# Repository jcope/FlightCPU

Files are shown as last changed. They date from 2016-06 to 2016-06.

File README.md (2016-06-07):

# FlightCPU
An embedded data logger for high altitude balloons

The Flight CPU is designed as a data logger for High Altitude Balloons. It is designed around the ATMEGA328P so it can easily be developed using Arduino tools. Most sensor modules communicate with the uC using I2C with the exception of the Humidity/Temp sensor which uses SPI. The data is then logged on the MicroSD card. 

Sensors include: Gyroscope, Compass, Temp/Humidity, Barometer.

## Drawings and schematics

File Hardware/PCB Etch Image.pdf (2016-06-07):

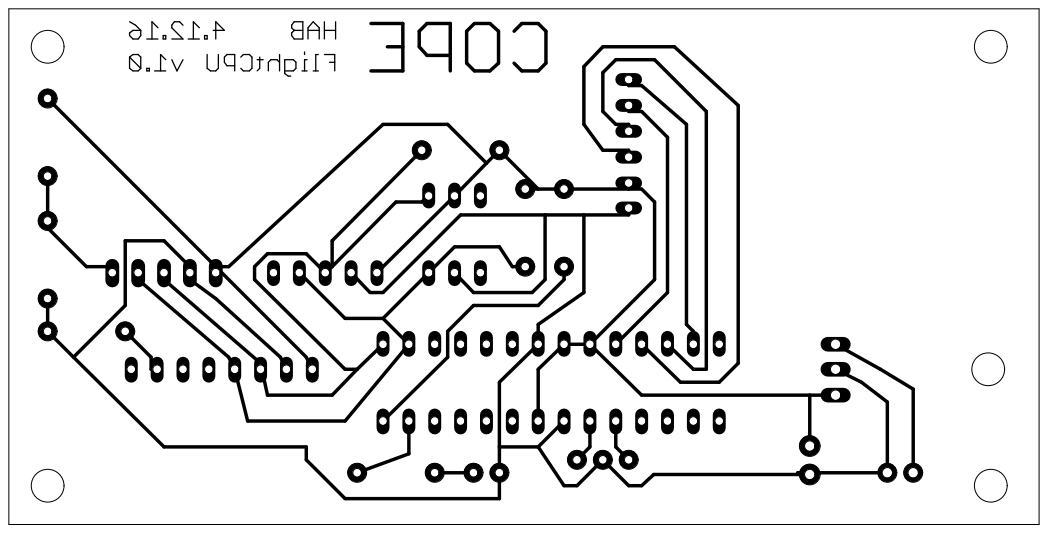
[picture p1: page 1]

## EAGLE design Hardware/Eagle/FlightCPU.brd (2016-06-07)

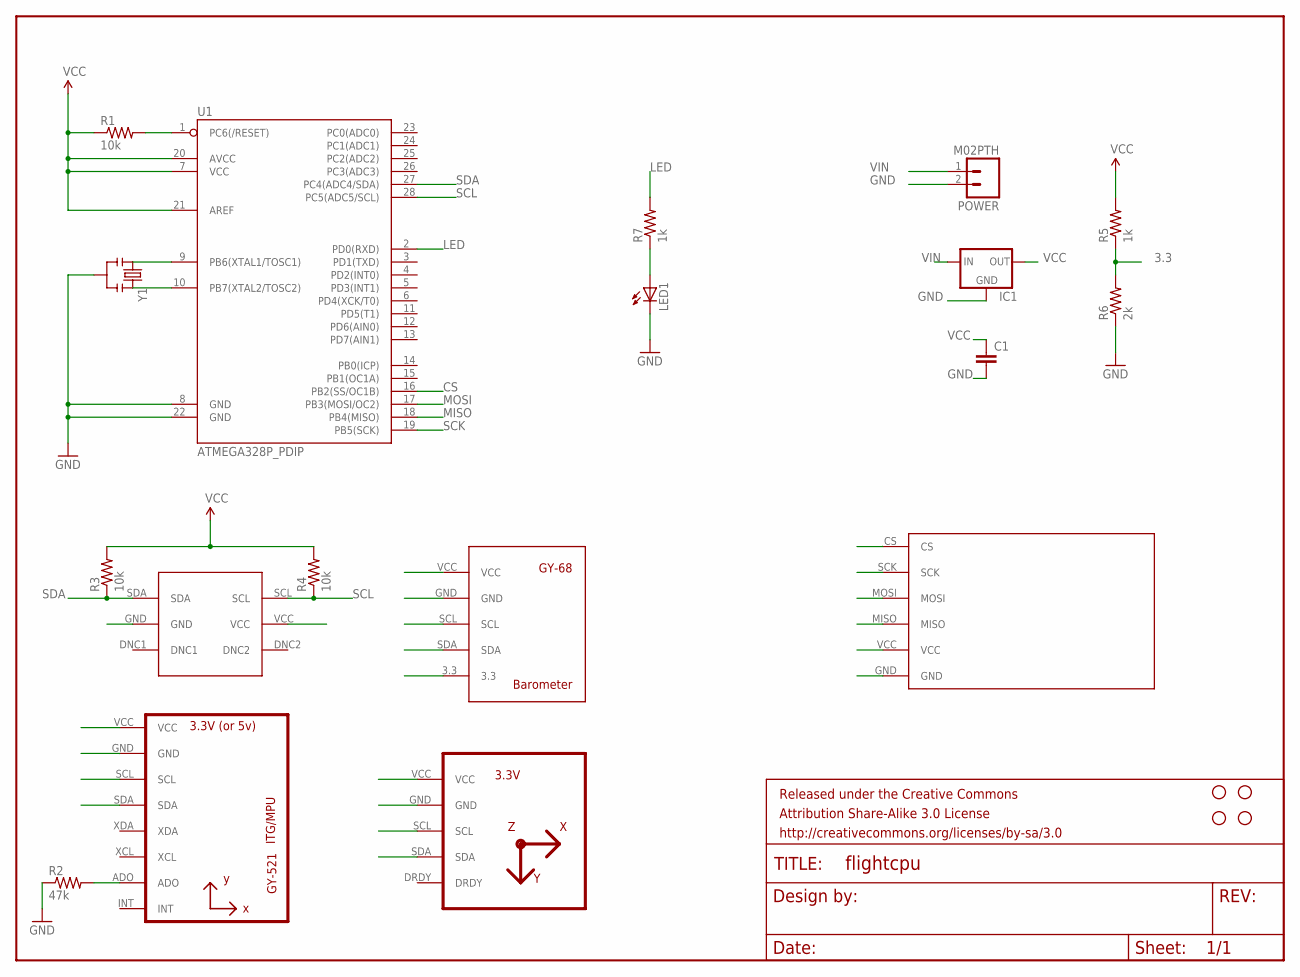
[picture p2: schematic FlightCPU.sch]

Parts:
C1: CAPKIT; CAP-PTH-SMALL-KIT
FRAME1: FRAME-LETTER; CREATIVE_COMMONS
IC1: V_REG_78XXSIDE; 78XXL
LED1: LED3MM
POWER: M02PTH; 1X02
R1, R3, R4: 10k; AXIAL-0.3
R2: 47k; AXIAL-0.3
R5, R7: 1k; AXIAL-0.3
R6: 2k; AXIAL-0.3
STANDOFF1, STANDOFF2, STANDOFF3, STANDOFF4: STAND-OFF
U1: ATMEGA328P_PDIP; DIL28-3
U2: GY-521MPU6050; GY-521
U3: HMC5883LGY-271; GY-271
U$1: SI7020_DIP; SI7020
U$2: GY-68
U$3: MICRO_SD; MICROSD
Y1: RESONATORPTH; RESONATOR-PTH

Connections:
3.3: R5.P$1 (1), R6.P$2 (2), U$2.3.3
CS: U1.16 (PB2(SS/OC1B)), U$3.CS
GND: C1.2, IC1.GND, LED1.K (C), POWER.2, R2.P$1 (1), R6.P$1 (1), U1.8 (GND), U1.22 (GND), U2.GND, U3.GND, U$1.GND, U$2.GND, U$3.GND, Y1.2
LED: R7.P$2 (2), U1.2 (PD0(RXD))
MISO: U1.18 (PB4(MISO)), U$3.MISO
MOSI: U1.17 (PB3(MOSI/OC2)), U$3.MOSI
unnamed: R1.P$2 (2), U1.1 (PC6(/RESET))
unnamed: U1.9 (PB6(XTAL1/TOSC1)), Y1.1
unnamed: U1.10 (PB7(XTAL2/TOSC2)), Y1.3
unnamed: LED1.A, R7.P$1 (1)
unnamed: R2.P$2 (2), U2.ADO
SCK: U1.19 (PB5(SCK)), U$3.SCK
SCL: R4.P$1 (1), U1.28 (PC5(ADC5/SCL)), U2.SCL, U3.SCL, U$1.SCL, U$2.SCL
SDA: R3.P$1 (1), U1.27 (PC4(ADC4/SDA)), U2.SDA, U3.SDA, U$1.SDA, U$2.SDA
VCC: C1.1, IC1.OUT, R1.P$1 (1), R3.P$2 (2), R4.P$2 (2), R5.P$2 (2), U1.7 (VCC), U1.20 (AVCC), U1.21 (AREF), U2.VCC, U3.VCC, U$1.VCC, U$2.VCC, U$3.VCC
VIN: IC1.IN, POWER.1

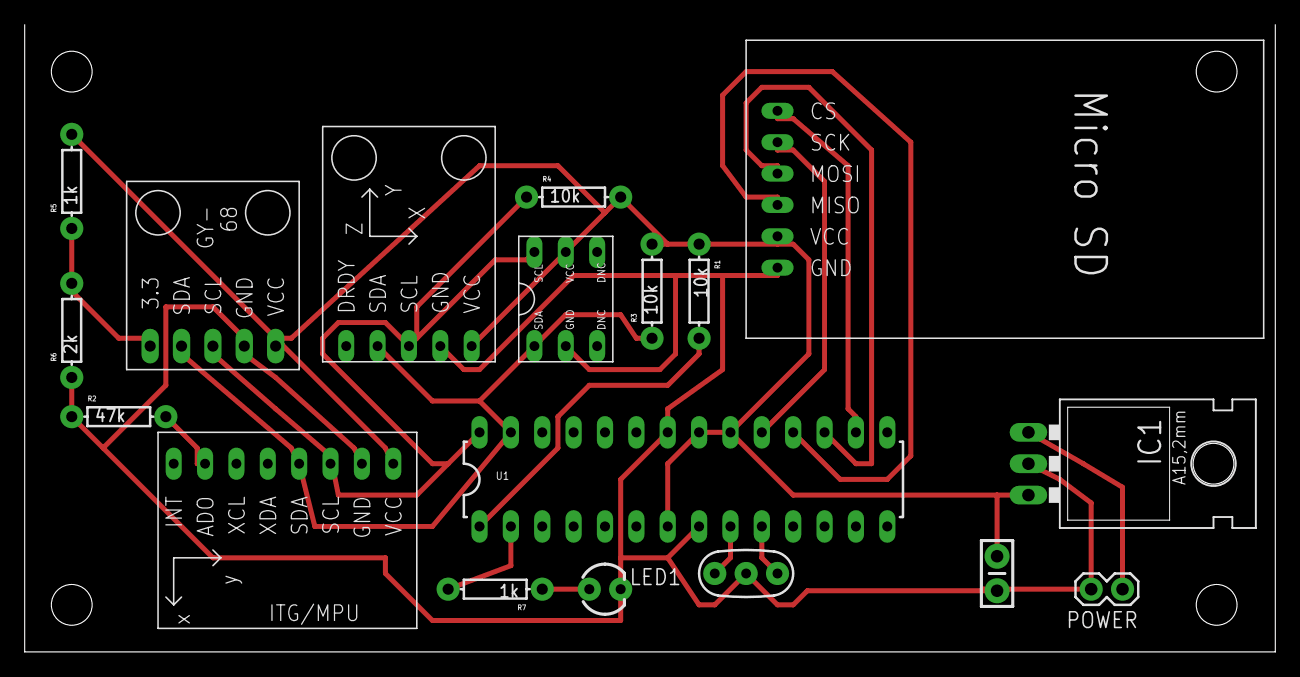
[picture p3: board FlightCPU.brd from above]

Board: 2 copper layers, 101.3 x 50.8 mm, 23 parts (0 on the bottom side), 16 nets.

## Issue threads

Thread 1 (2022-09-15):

SD Card Issues

svetgeorgiev, 2022-09-15:
main: In function 'void writeToSD(double)':
main:343: error: no matching function for call to 'SDClass::open(const __FlashStringHelper*, int)'
   dFile = SD.open(F("COPE01.txt"), FILE_WRITE);
                                              ^
In file included from C:\Users\B0lero\Desktop\main\main.ino:74:0:
C:\Program Files (x86)\Arduino\hardware\teensy\avr\libraries\SD\src/SD.h:181:7: note: candidate: virtual File SDClass::open(const char*, uint8_t)
  File open(const char *filepath, uint8_t mode = FILE_READ) {
       ^
C:\Program Files (x86)\Arduino\hardware\teensy\avr\libraries\SD\src/SD.h:181:7: note:   no known conversion for argument 1 from 'const __FlashStringHelper*' to 'const char*'
main: In function 'void writeToSD(double, int)':
main:359: error: no matching function for call to 'SDClass::open(const __FlashStringHelper*, int)'
   dFile = SD.open(F("COPE01.txt"), FILE_WRITE);
                                              ^
In file included from C:\Users\B0lero\Desktop\main\main.ino:74:0:
C:\Program Files (x86)\Arduino\hardware\teensy\avr\libraries\SD\src/SD.h:181:7: note: candidate: virtual File SDClass::open(const char*, uint8_t)
  File open(const char *filepath, uint8_t mode = FILE_READ) {
       ^
C:\Program Files (x86)\Arduino\hardware\teensy\avr\libraries\SD\src/SD.h:181:7: note:   no known conversion for argument 1 from 'const __FlashStringHelper*' to 'const char*'
main: In function 'void writeToSD(String)':
main:375: error: no matching function for call to 'SDClass::open(const __FlashStringHelper*, int)'
   dFile = SD.open(F("COPE01.txt"), FILE_WRITE);
                                              ^
In file included from C:\Users\B0lero\Desktop\main\main.ino:74:0:
C:\Program Files (x86)\Arduino\hardware\teensy\avr\libraries\SD\src/SD.h:181:7: note: candidate: virtual File SDClass::open(const char*, uint8_t)
  File open(const char *filepath, uint8_t mode = FILE_READ) {
       ^
C:\Program Files (x86)\Arduino\hardware\teensy\avr\libraries\SD\src/SD.h:181:7: note:   no known conversion for argument 1 from 'const __FlashStringHelper*' to 'const char*'
main: In function 'void writeToSDln(double)':
main:395: error: no matching function for call to 'SDClass::open(const __FlashStringHelper*, int)'
   dFile = SD.open(F("COPE01.txt"), FILE_WRITE);
                                              ^
In file included from C:\Users\B0lero\Desktop\main\main.ino:74:0:
C:\Program Files (x86)\Arduino\hardware\teensy\avr\libraries\SD\src/SD.h:181:7: note: candidate: virtual File SDClass::open(const char*, uint8_t)
  File open(const char *filepath, uint8_t mode = FILE_READ) {
       ^
C:\Program Files (x86)\Arduino\hardware\teensy\avr\libraries\SD\src/SD.h:181:7: note:   no known conversion for argument 1 from 'const __FlashStringHelper*' to 'const char*'
main: In function 'void writeToSDln(double, int)':
main:411: error: no matching function for call to 'SDClass::open(const __FlashStringHelper*, int)'
   dFile = SD.open(F("COPE01.txt"), FILE_WRITE);
                                              ^
In file included from C:\Users\B0lero\Desktop\main\main.ino:74:0:
C:\Program Files (x86)\Arduino\hardware\teensy\avr\libraries\SD\src/SD.h:181:7: note: candidate: virtual File SDClass::open(const char*, uint8_t)
  File open(const char *filepath, uint8_t mode = FILE_READ) {
       ^
C:\Program Files (x86)\Arduino\hardware\teensy\avr\libraries\SD\src/SD.h:181:7: note:   no known conversion for argument 1 from 'const __FlashStringHelper*' to 'const char*'
main: In function 'void writeToSDln(String)':
main:427: error: no matching function for call to 'SDClass::open(const __FlashStringHelper*, int)'
   dFile = SD.open(F("COPE01.txt"), FILE_WRITE);
                                              ^
In file included from C:\Users\B0lero\Desktop\main\main.ino:74:0:
C:\Program Files (x86)\Arduino\hardware\teensy\avr\libraries\SD\src/SD.h:181:7: note: candidate: virtual File SDClass::open(const char*, uint8_t)
  File open(const char *filepath, uint8_t mode = FILE_READ) {
       ^

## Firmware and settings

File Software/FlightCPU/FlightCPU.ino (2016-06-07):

//Common
#include "Wire.h"
#include "I2Cdev.h"

/********************
    Pressure
*/
#include <SFE_BMP180.h>
// You will need to create an SFE_BMP180 object, here called "pressure":
SFE_BMP180 pressure;
double baselineP; // baseline pressure
void pressureFunc();
void getTempPressure(double &T, double &P);


/********************
    Compass-Magmometer
*/

#include "HMC5883L.h"
// class default I2C address is 0x1E
// specific I2C addresses may be passed as a parameter here
// this device only supports one I2C address (0x1E)
HMC5883L mag;
int16_t mx, my, mz;
void compassFunc();



/********************
    Acceler-Gyro
*/
#include "MPU6050.h"
// class default I2C address is 0x68
// specific I2C addresses may be passed as a parameter here
// AD0 low = 0x68 (default for InvenSense evaluation board)
// AD0 high = 0x69
MPU6050 accelgyro;
//MPU6050 accelgyro(0x69); // <-- use for AD0 high
int16_t ax, ay, az;
int16_t gx, gy, gz;

// uncomment "OUTPUT_READABLE_ACCELGYRO" if you want to see a tab-separated
// list of the accel X/Y/Z and then gyro X/Y/Z values in decimal. Easy to read,
// not so easy to parse, and slow(er) over UART.
#define OUTPUT_READABLE_ACCELGYRO

// uncomment "OUTPUT_BINARY_ACCELGYRO" to send all 6 axes of data as 16-bit
// binary, one right after the other. This is very fast (as fast as possible
// without compression or data loss), and easy to parse, but impossible to read
// for a human.
//#define OUTPUT_BINARY_ACCELGYRO

void accelGyroFunc();
void accelGyroFactoryReset();


/********************
   Humidity/Temp
*/
void humdTempFunc();


/********************
   SD card datalogger
   SD card attached to SPI bus as follows:
 ** MOSI - pin 11
 ** MISO - pin 12
 ** CLK - pin 13
 ** CS - pin 4
*/
#include <SPI.h>
#include <SD.h>
const int chipSelect = 4;
File dataFile;
void initDataFile();
void writeToSD(String dataLine);
void writeToSD(double dataLine);
void writeToSDln(double dataLine);
void writeToSDln(String dataLine);


/********************
    IO
*/
#define LED_PIN 0
bool blinkState = false;
unsigned long t;


void setup() {
  // Initialize the LED- Must be first for data indicators
  pinMode(LED_PIN, OUTPUT);

  // join I2C bus (I2Cdev library doesn't do this automatically)
  Wire.begin();

  //Initialize SD Card
  initDataFile();

  // initialize device
  mag.initialize();
  accelgyro.initialize();

  // verify connection
  writeToSDln(mag.testConnection() ? F("HMC5883L connection successful") : F("HMC5883L connection failed"));      //Compass
  writeToSDln(pressure.begin() ? F("BMP180 connection successful") : F("BMP180 connection failed"));              //Barometer
  writeToSDln(accelgyro.testConnection() ? F("MPU6050 connection successful") : F("MPU6050 connection failed"));  //AccellGyro

  //Calibrate any baselines
  // Get the baseline pressure:
  double T;// through away temp
  getTempPressure(T,baselineP);
}

void loop() {
  //Log time
  t = millis();
  writeToSD("t,");
  writeToSDln(t);
  
  blinkState = !blinkState;
  digitalWrite(LED_PIN, blinkState);
  compassFunc();
  delay(250);
  
  blinkState = !blinkState;
  digitalWrite(LED_PIN, blinkState);
  accelGyroFunc();
  delay(250);
  

  
  humdTempFunc();
  delay(500);
  

  compassFunc();
  delay(250);
  accelGyroFunc();
  delay(250);

  pressureFunc();
  delay(500);
}

//C,mx,my,mx,h
//Compass,magX,magY,magZ,heading
void compassFunc() {
  writeToSD(F("C,"));
  // read raw heading measurements from device
  mag.getHeading(&mx, &my, &mz);

  // display tab-separated gyro x/y/z values
  writeToSD(mx); writeToSD(",");
  writeToSD(my); writeToSD(F(","));
  writeToSD(mz); writeToSD(F(","));

  // To calculate heading in degrees. 0 degree indicates North
  float heading = atan2(my, mx);
  if (heading < 0) {
    heading += 2 * M_PI;
  }
  writeToSDln(heading * 180 / M_PI);
}

//B,t,p,a
//Barameter,Temp(f),Pressure(mb),Altitude(ft)
void pressureFunc() {
  double T, P, A;
  writeToSD(F("B,"));

  getTempPressure(T, P);

  //We now have Pessure, Temp.. Go Calculate Altitude
  //Pressure
  writeToSD(P, 2);
  //Temp
  writeToSD(F(","));
  writeToSD((9.0 / 5.0)*T + 32.0, 2);
  //Altitude
  writeToSD(F(","));
  A = pressure.altitude(P, baselineP);
  writeToSDln(A * 3.28084, 0); //Altitude in ft
}
void getTempPressure(double &T, double &P) {
  char status;
  // You must first get a temperature measurement to perform a pressure reading.

  // Start a temperature measurement:
  // If request is successful, the number of ms to wait is returned.
  // If request is unsuccessful, 0 is returned.

  status = pressure.startTemperature();
  if (status != 0)
  {
    // Wait for the measurement to complete:

    delay(status);

    // Retrieve the completed temperature measurement:
    // Note that the measurement is stored in the variable T.
    // Use '&T' to provide the address of T to the function.
    // Function returns 1 if successful, 0 if failure.

    status = pressure.getTemperature(T);
    if (status != 0)
    {
      // Start a pressure measurement:
      // The parameter is the oversampling setting, from 0 to 3 (highest res, longest wait).
      // If request is successful, the number of ms to wait is returned.
      // If request is unsuccessful, 0 is returned.

      status = pressure.startPressure(3);
      if (status != 0)
      {
        // Wait for the measurement to complete:
        delay(status);

        // Retrieve the completed pressure measurement:
        // Note that the measurement is stored in the variable P.
        // Use '&P' to provide the address of P.
        // Note also that the function requires the previous temperature measurement (T).
        // (If temperature is stable, you can do one temperature measurement for a number of pressure measurements.)
        // Function returns 1 if successful, 0 if failure.

        status = pressure.getPressure(P, T);
        if (status != 0)
        {



        }
        else writeToSDln(F("e1")); //error retrieving pressure
      }
      else writeToSDln(F("e2")); //error starting pressure
    }
    else writeToSDln(F("e3")); //error retrieving temp
  }
  else writeToSDln(F("e4")); //error starting temp
}
//ax,ay,az,gz,gx,gy
void accelGyroFunc() {
  // read raw accel/gyro measurements from device
  accelgyro.getMotion6(&ax, &ay, &az, &gx, &gy, &gz);

  // these methods (and a few others) are also available
  //accelgyro.getAcceleration(&ax, &ay, &az);
  //accelgyro.getRotation(&gx, &gy, &gz);

#ifdef OUTPUT_READABLE_ACCELGYRO
  // display tab-separated accel/gyro x/y/z values
  writeToSD("a/g,");
  writeToSD(ax); writeToSD(F(","));
  writeToSD(ay); writeToSD(F(","));
  writeToSD(az); writeToSD(F(","));
  writeToSD(gx); writeToSD(F(","));
  writeToSD(gy); writeToSD(F(","));
  writeToSDln(gz);
#endif

#ifdef OUTPUT_BINARY_ACCELGYRO
  Serial.write((uint8_t)(ax >> 8)); Serial.write((uint8_t)(ax & 0xFF));
  Serial.write((uint8_t)(ay >> 8)); Serial.write((uint8_t)(ay & 0xFF));
  Serial.write((uint8_t)(az >> 8)); Serial.write((uint8_t)(az & 0xFF));
  Serial.write((uint8_t)(gx >> 8)); Serial.write((uint8_t)(gx & 0xFF));
  Serial.write((uint8_t)(gy >> 8)); Serial.write((uint8_t)(gy & 0xFF));
  Serial.write((uint8_t)(gz >> 8)); Serial.write((uint8_t)(gz & 0xFF));
#endif

}
//S,t,h
//Si7020,Temp(f),Humidity(%,relative)
void humdTempFunc() {
  writeToSD(F("S,"));

  int index = 0;
  word data = 0;
  byte readData [20];

  //**************Request Temp
  Wire.beginTransmission(0x40);
  Wire.write(0xE3); //Hold Master mode- no hold doesn't seem to work
  Wire.endTransmission();
  //Read the value back
  Wire.requestFrom(0x40, 2);
  while (Wire.available()) {
    readData[index++] = Wire.read();
  }
  //Process the Data
  data = readData[0] << 8;
  data = data | readData[1];
  float tempC;
  tempC = (175.72 * data) / 65536 - 46.85;
  float tempF;
  tempF = (tempC * 9) / 5 + 32.0;
  writeToSD(tempF, 4);
  writeToSD(F(","));
  delay(30); //Arbitrary delay between commands


  //**************Read Humid
  index = 0;
  Wire.beginTransmission(0x40);
  Wire.write(0xE5); //Hold Master mode- no hold doesn't seem to work
  Wire.endTransmission();
  //Read the value back
  Wire.requestFrom(0x40, 2);
  while (Wire.available()) {
    readData[index++] = Wire.read();
  }
  //Process the Data
  data = readData[0] << 8;
  data = data | readData[1];
  float relativeHumid;
  relativeHumid = (125.0 * data) / 65536 - 6.0;
  writeToSDln(relativeHumid, 2);
}
/**************************************************************************
   SD CARD
*/
void initDataFile() {
  // make sure that the default chip select pin is set to
  // output, even if you don't use it:
  pinMode(10, OUTPUT);

  // see if the card is present and can be initialized:
  if (!SD.begin(chipSelect)) {
    //If we could not initialize, blink LED
    while (1) {
      delay(250);
      blinkState = !blinkState;
      digitalWrite(LED_PIN, blinkState);
    }
    return;
  }
}


void writeToSD(double data) {
  File dFile;
  dFile = SD.open(F("COPE01.txt"), FILE_WRITE);

  if (dFile) {
    dFile.print(data);
    dFile.close();
  }
  else {
    for (int i = 0; i < 4; i++) {
      delay(500);
      blinkState = !blinkState;
      digitalWrite(LED_PIN, blinkState);
    }
  }
}
void writeToSD(double data, int percision) {
  File dFile;
  dFile = SD.open(F("COPE01.txt"), FILE_WRITE);

  if (dFile) {
    dFile.print(data, percision);
    dFile.close();
  }
  else {
    for (int i = 0; i < 4; i++) {
      delay(500);
      blinkState = !blinkState;
      digitalWrite(LED_PIN, blinkState);
    }
  }
}
void writeToSD(String line) {
  File dFile;
  dFile = SD.open(F("COPE01.txt"), FILE_WRITE);

  if (dFile) {
    dFile.print(line);
    dFile.close();
  }
  else {
    for (int i = 0; i < 4; i++) {
      delay(500);
      blinkState = !blinkState;
      digitalWrite(LED_PIN, blinkState);
    }
  }
}

/******************* New Line ***********

*/

void writeToSDln(double data) {
  File dFile;
  dFile = SD.open(F("COPE01.txt"), FILE_WRITE);

  if (dFile) {
    dFile.println(data);
    dFile.close();
  }
  else {
    for (int i = 0; i < 4; i++) {
      delay(500);
      blinkState = !blinkState;
      digitalWrite(LED_PIN, blinkState);
    }
  }
}
void writeToSDln(double data, int percision) {
  File dFile;
  dFile = SD.open(F("COPE01.txt"), FILE_WRITE);

  if (dFile) {
    dFile.println(data, percision);
    dFile.close();
  }
  else {
    for (int i = 0; i < 4; i++) {
      delay(500);
      blinkState = !blinkState;
      digitalWrite(LED_PIN, blinkState);
    }
  }
}
void writeToSDln(String line) {
  File dFile;
  dFile = SD.open(F("COPE01.txt"), FILE_WRITE);

  if (dFile) {
    dFile.println(line);
    dFile.close();
  }
  else {
    for (int i = 0; i < 4; i++) {
      delay(500);
      blinkState = !blinkState;
      digitalWrite(LED_PIN, blinkState);
    }
  }
}

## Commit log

2016-06-07 Initial Software Commit
    Added Arduino Project File- as well as 3rd party libraries.
    Added Datasheets
2016-06-07 Initial Hardware Commit
    Added Eagle Library containing all the components, and the eagle
    project files containing the schematic and the pcb layout.
    Also added pdf containing the image used to etch the pcb.
    [FlightCPU.brd, FlightCPU.sch]

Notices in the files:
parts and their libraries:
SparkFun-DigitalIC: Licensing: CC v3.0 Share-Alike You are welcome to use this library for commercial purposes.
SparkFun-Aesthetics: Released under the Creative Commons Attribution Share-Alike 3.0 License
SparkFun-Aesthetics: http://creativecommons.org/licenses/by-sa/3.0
